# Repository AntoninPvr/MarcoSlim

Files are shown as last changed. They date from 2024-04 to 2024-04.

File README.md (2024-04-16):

<h1 align="center">
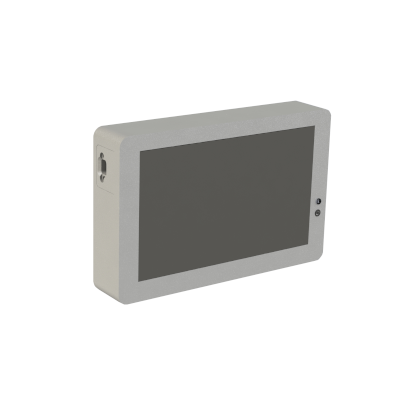
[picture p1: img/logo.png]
MarcoSlim Logo
    </a>
    <br>
    MarcoSlim
</h1>





    ⚠️ DISCONTINUED
    This project is discontinued and will not be updated anymore.
    Please refer to the new version of the Marco project

### New version MarcoX is available here : https://github.com/AntoninPvr/MarcoX

---

## Preface 
MarcoSlim is an upgrade of original Marco. Project had been launched during the 2023 BDE of Télécom Physique Strasbourg. Original Marco was based on Raspberry PI and old style resistive screen and 3 meters of cables and adapters hardly stuff in rectangular 3D printed case.

This new version is based on Orange PI zero 2W with a 7" capacitive touch screen. This modernized versiona aims to be more reliable and compact with a new RFID reader.

Software was also modernized and is available here : https://github.com/LOISGALLAUD/MARCONEO

Marco is a project that aims to create a payment terminal for a school BDE (French equivalent of Student Union). It is based on a RFID card system. The terminal is used by the students to pay for their meals or drinks. The terminal is connected to a self-hosted server that manages the accounts of the students. This terminal act as cash register.

This project is related to InsidePSBS app. Students can check their account and history on this mobile app available on IOS and Android. https://github.com/info-telecom-strasbourg/InsidePSBS (Reserved to TPS and ESBS students)

<p float="left">
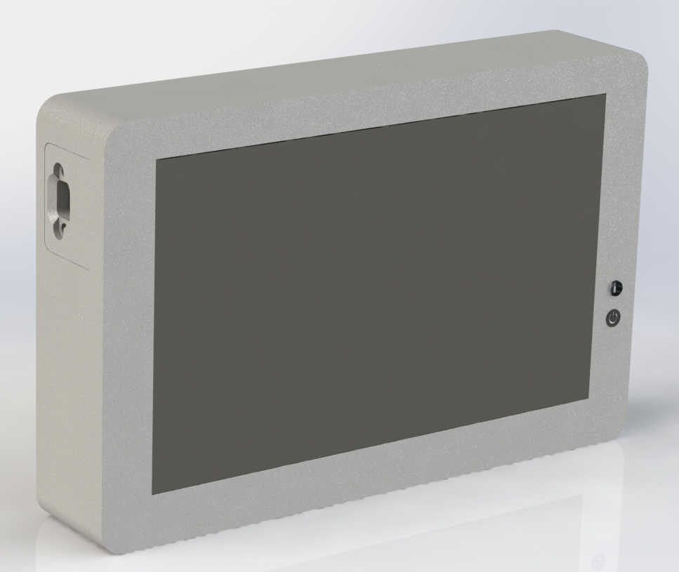
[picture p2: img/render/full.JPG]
  
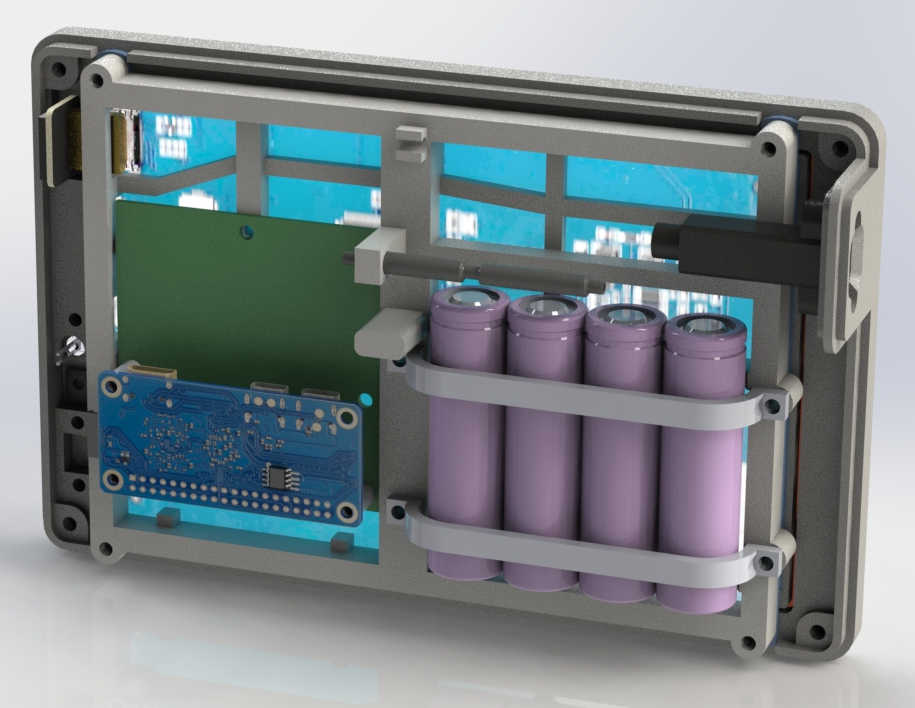
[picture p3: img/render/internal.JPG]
   
</p>

## Specifications

* **Screen**: 7" capacitive touch screen
* **RFID reader**: 125kHz compatible
* **Power supply**: USB-C 5V 3A
* **SBC**: Orange PI zero 2W
    * SoC: Allwinner H618 quad-core Cortex-A53 @ 1.5GHz
    * RAM: 1GB LPDDR4
    * Wi-Fi: 802.11 ac (Wi-Fi 5)
    * Bluetooth: 5.0
* **Battery**: 29.6Wh Li-ion (4x 3.7V 2000mAh)
* **Dimensions**:
    * Length: 200mm
    * Depth: 129mm
    * Height: 38mm

## Shopping list

### Electronic parts

* Orange PI zero 2W with 1GB RAM or more
* Micro SD card 16GB ore more, U3 speed class or more
* 7" Waveshare touch screen or compatible with HDMI input
* 125kHz RFID reader
* 4x 3.7V 2000mAh Li-ion battery
* USB-C power supply
* mini HDMI to HDMI 100mm cable: A2 to C1
* USB-C to micro usb 100mm cable: W3R to T1B
* USB-C pannel 17mm center distance mount connector 20mm

    ---

### Mechanical parts
* M4 screws 16mm x4
* M4 inserts x4
* M3 screws 10mm x15
* M3 inserts x15

    ---
### Parts details
| | |
|---|---|
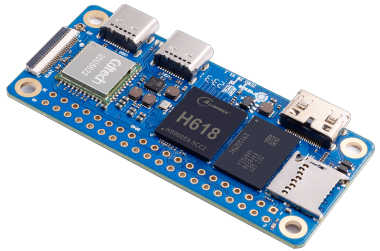
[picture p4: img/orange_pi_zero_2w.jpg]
Orange PI zero 2W
| Orange PI zero 2W |<p align="right"> 
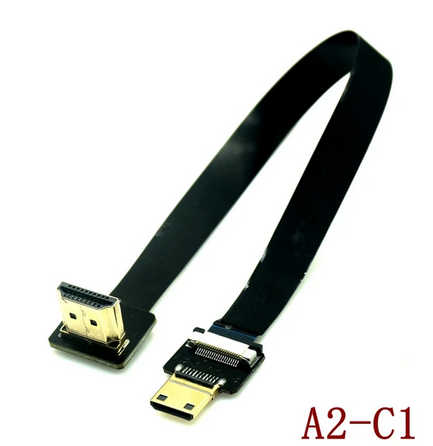
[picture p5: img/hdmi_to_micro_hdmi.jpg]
HDMI to Micro HDMI adapter
|Mini HDMI to HDMI 100mm cable: (A2 to C1). Large side of HDMI is on ribbon cable side. Mini HDMI large side is on ribbon connector side.  | |
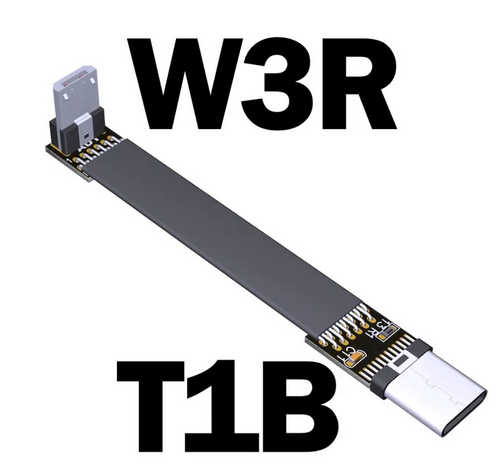
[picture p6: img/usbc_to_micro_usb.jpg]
HDMI to Micro HDMI adapter
|USB-C to micro usb 100mm cable: W3R to T1B||
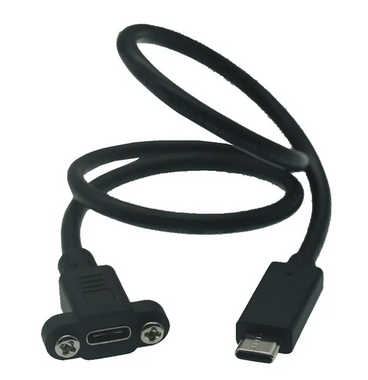
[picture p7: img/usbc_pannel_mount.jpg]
|USB-C pannel 17mm center distance mount connector 200mm||

### Screen

Screen is 7" Waveshare touch screen or compatible with HDMI input it can be a compatible one as long as it has the same connectors and the same size.

<p align="center">
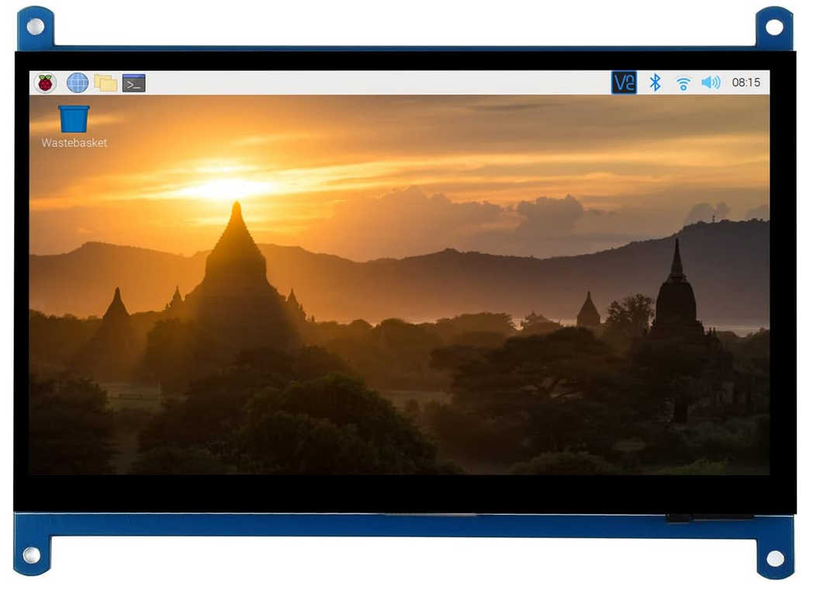
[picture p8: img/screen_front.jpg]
Front
    
&nbsp;
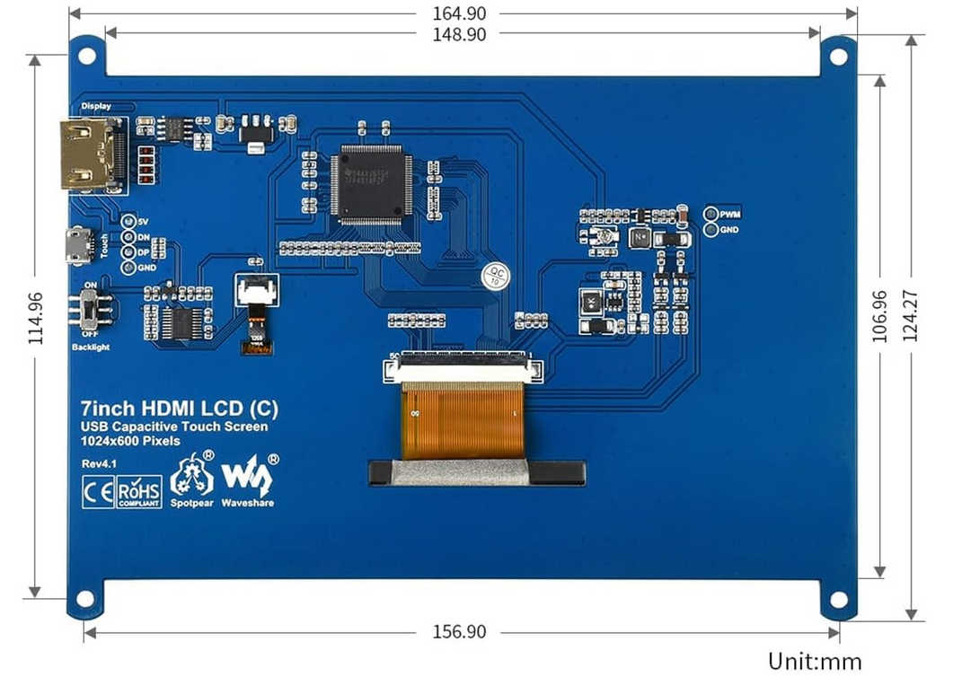
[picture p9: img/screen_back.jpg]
Screen BAck
    
</p>

## 3D printed parts

All parts are in `.stl` format. They are designed to be printed without support.

### Printer settings

Tested settings, but feel free to adapt them to your printer and material.:

* Layer height: 0.2mm
* Infill: 20%
* Nozzle diameter: 0.4mm
* Material: PLA or PETG

*Note: PTEG is recommended for better water and UV resistance.*

### All parts

<p align="center">
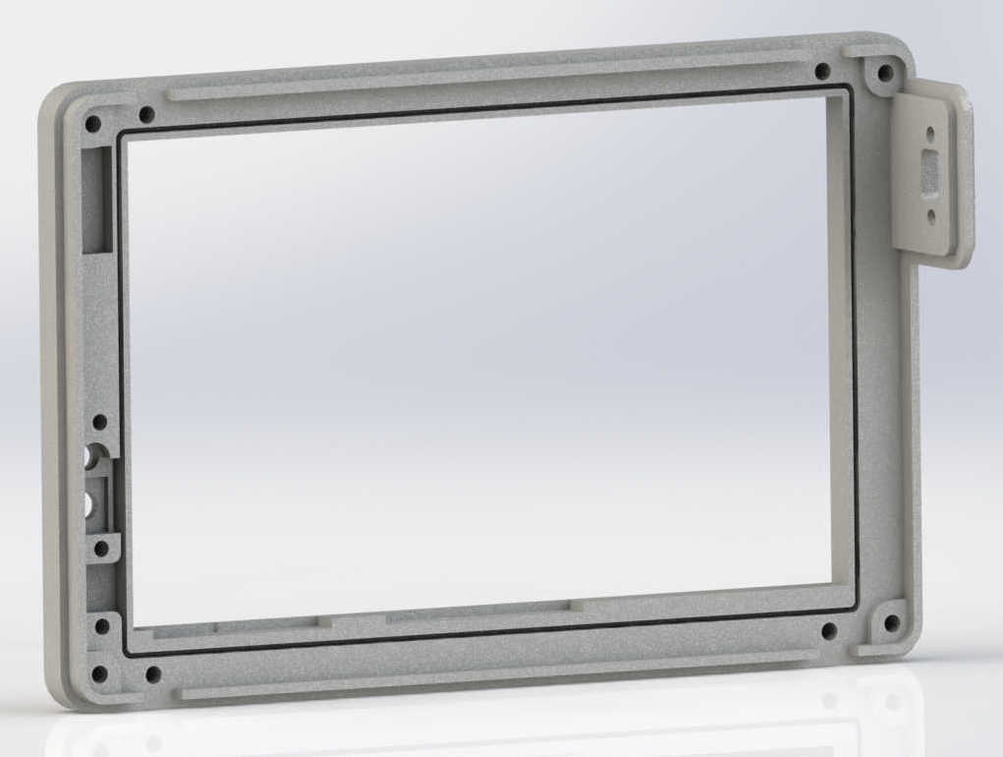
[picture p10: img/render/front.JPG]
Screen front
    
&nbsp;
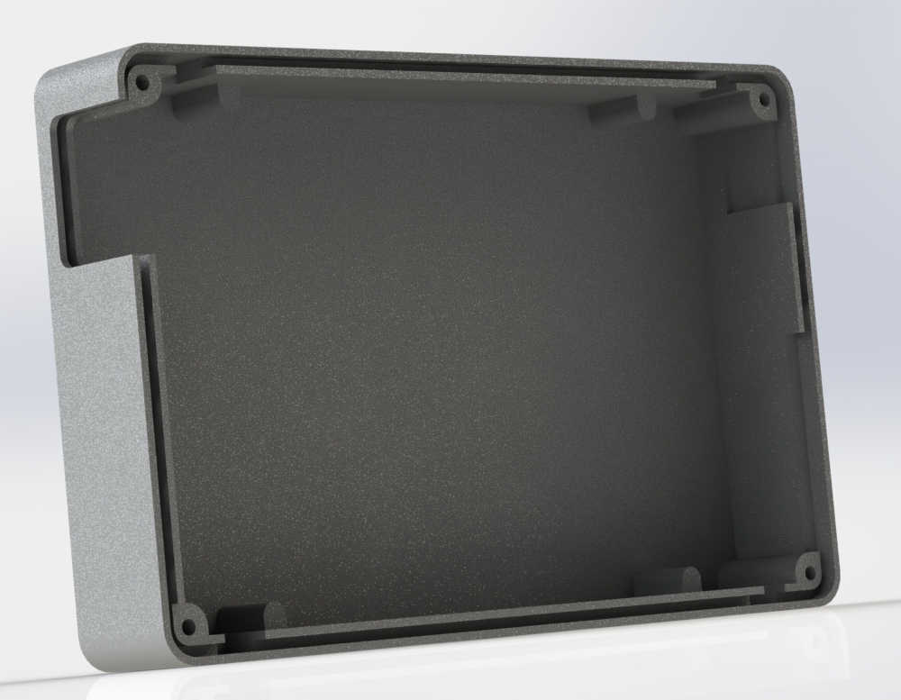
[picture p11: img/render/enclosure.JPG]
Cover
    
&nbsp;
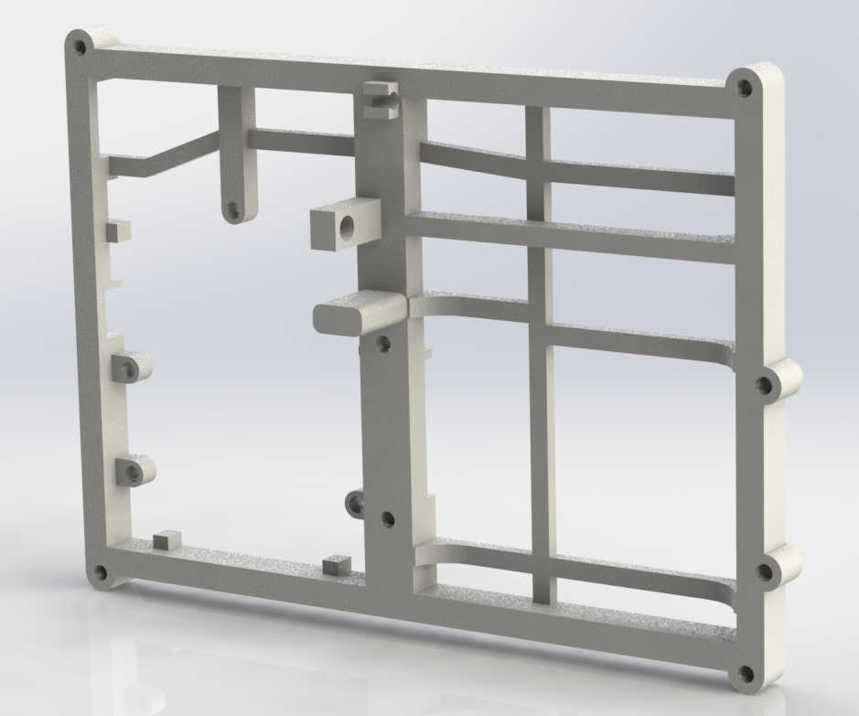
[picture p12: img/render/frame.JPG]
Frame
    
</p>

### Front

**File:** [front.STL](https://github.com/AntoninPvr/MarcoSlim/blob/main/front.STL)

The front cover hold the screen and allow it to be attached without overthickness. It also includes the RFID reader coil use for card detection, USB-C charging hole, power activity LED and Power button. This part is attached to the enclosure with 4 M4 screws, and provide a sort of seal to prevent dust and water to enter the enclosure.

*Note: clearance for sealing are very tight. This make 3D printing more difficult and printer dependent.*

### Internal frame

**File:** [internal_frame.STL](https://github.com/AntoninPvr/MarcoSlim/blob/main/internal_frame.STL)

This frame is attached to the screen and is used to mount Orange PI, Li-ion batteries, PCB and Wi-Fi antenna.

*Note: For this part adding support may improve print quality*

### Cover

**File:** [cover.STL](https://github.com/AntoninPvr/MarcoSlim/blob/main/cover.STL)

The back cover is used to close the enclosure. It is attached to the enclosure with 4 M4 screws.

*Note: clearance for sealing are very tight. This make 3D printing more difficult and printer dependent.*

### Orange PI Standoff

**File:** [orange_pi_standoff.STL](https://github.com/AntoninPvr/MarcoSlim/blob/main/orange_pi_standoff.STL)

Standoff are used to maintain Orange PI in place and add spacing for electronics components bellow. They are attached to the internal frame with 3 M3 screws.

### Battery holder 

**File:** [18650_4_holder.STL](https://github.com/AntoninPvr/MarcoSlim/blob/main/18650_4_holder.STL)

Battery holder is used to maintain 4 Li-ion batteries in place. It is attached to the internal frame with 4 M3 screws.

### Power button

**File:** [power_button.STL](https://github.com/AntoninPvr/MarcoSlim/blob/main/power_button.STL)

Power button.

## Electronics

### RFID reader

RFID reader is connected to Orange PI with either USB if the reader use is the classic USB reader that act as a keyboard or GPIO if the reader is custom made on PCB.

The RFID coil is placed in the front cover arround the screen. By this way the card can be detected by the reader when the card is hold in the user hand when he interact with the screen. This is a way to make the user experience more intuitive. Coil is connected to a tiny PCB with a connector that is attached to the front cover with 2 M3 screws. (see front cover bellow)

<p align="center">
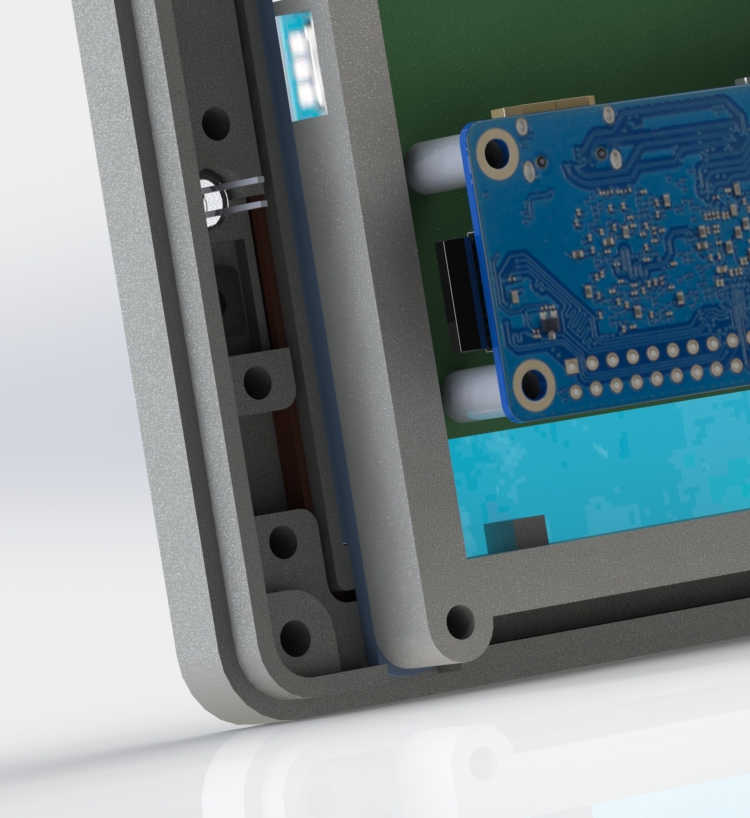
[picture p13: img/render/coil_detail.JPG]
Coil details
    
</p>

But the screen is made with a large metal plate that disturb the magnetic field of the coil. After multiple tests this idea was abandoned in favor of a more classic placement of the coil with the new MarcoX version.

### Power button and activity LED

Power button is connected to PCB with a 2 pin connector and trigger Orange PI zero 2W boot. It is placed in the front cover and is used to power on and off the terminal.

Activity LED is bicolor and connected to PCB with a 3 pin connector. It is placed in the front cover to indicate the charging status of the terminal.

<p align="center">
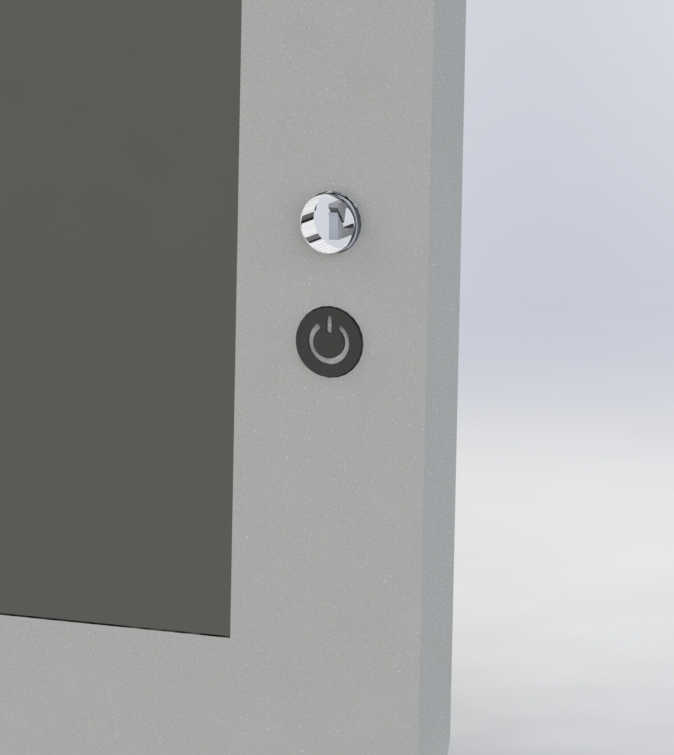
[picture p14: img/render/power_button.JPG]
    
</p>

## Related projects

* #### New version MarcoX is available here :
    > https://github.com/AntoninPvr/MarcoX

    <p align="left">
        
    &nbsp;
        
    &nbsp;
        
    </p>    
---

* #### Software associated with MarcoX is available here :
    > https://github.com/LOISGALLAUD/MARCONEO

    <p align="left">
        Screen front
    &nbsp;
        Screen BAck
    &nbsp;
        Screen BAck
    </p>
---

* #### Mobile App InsidePSBS source is available here :
    > https://github.com/info-telecom-strasbourg/InsidePSBS
    
<p align="right">
    <a href="https://app.its-tps.fr" target="_blank">
        
    </a>
 </p>

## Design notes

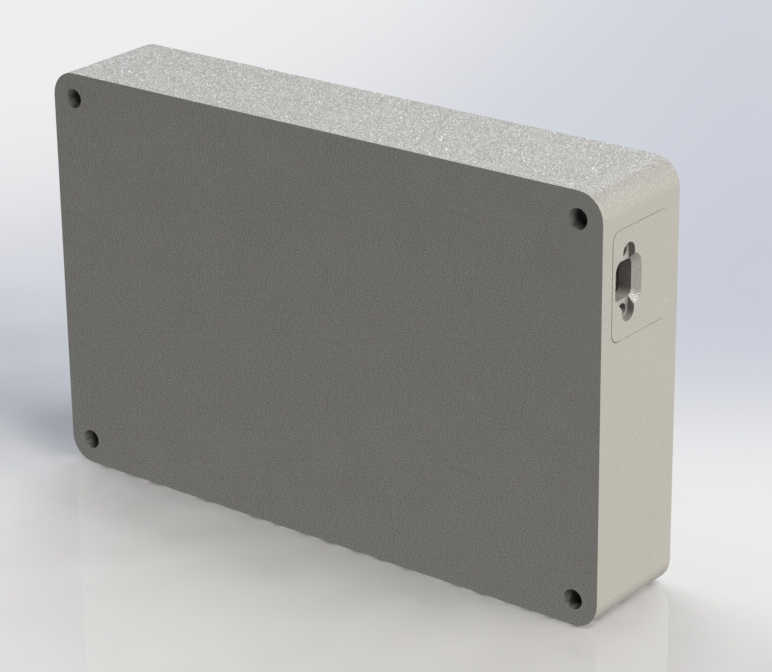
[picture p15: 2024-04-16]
img/render/back.JPG

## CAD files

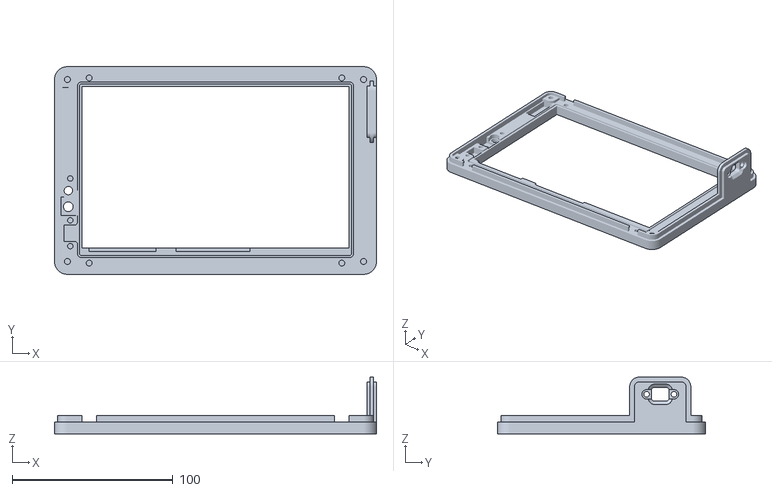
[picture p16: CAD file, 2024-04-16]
front.STL
200.0 x 129.0 x 35.3

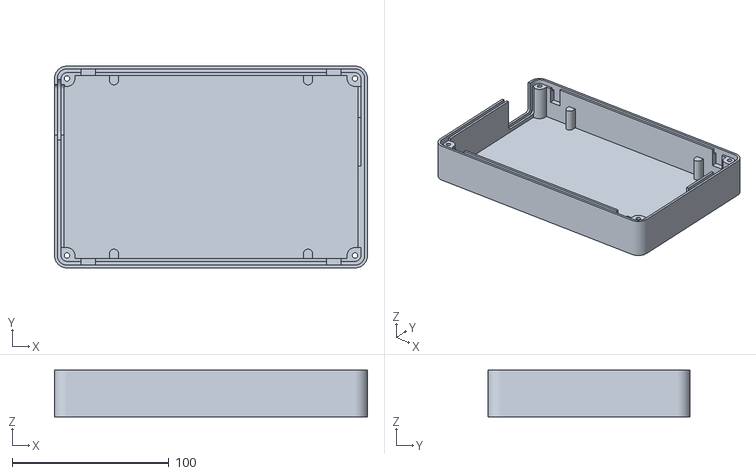
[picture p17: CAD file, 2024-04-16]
cover.STL
200.0 x 129.0 x 30.0

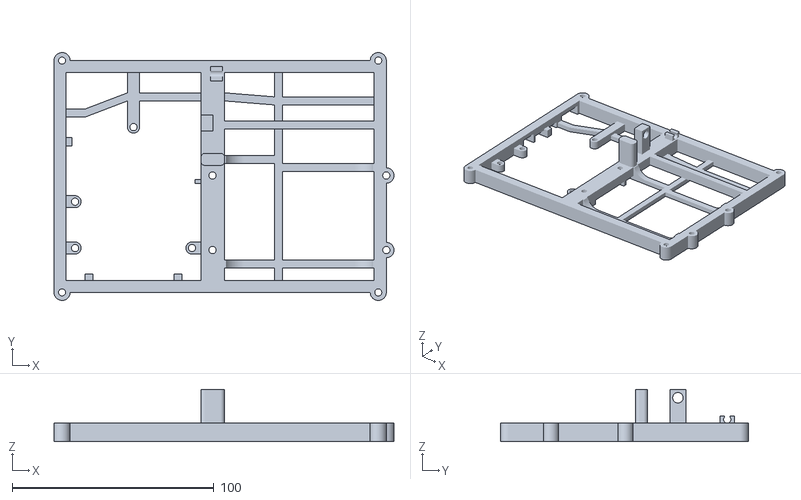
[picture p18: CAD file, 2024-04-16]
internal_frame.STL
168.7 x 123.0 x 26.0

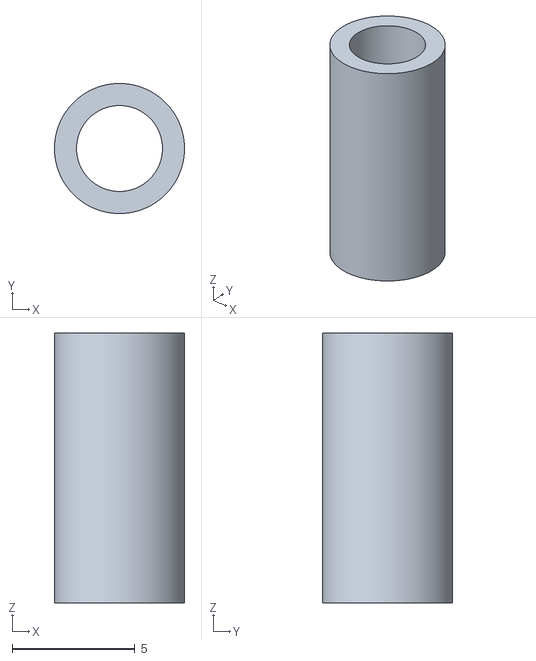
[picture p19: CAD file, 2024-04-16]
orange_pi_standoff.STL
5.30 x 5.30 x 11.0

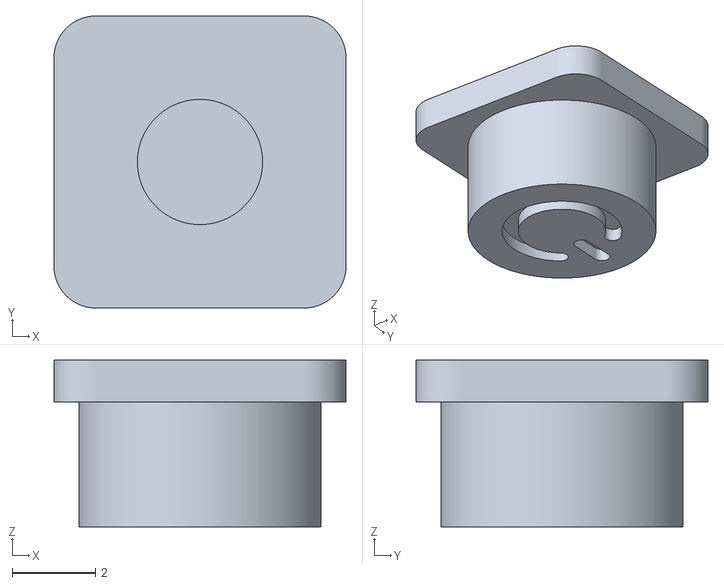
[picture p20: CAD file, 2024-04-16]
power_button.STL
7.00 x 7.00 x 4.00

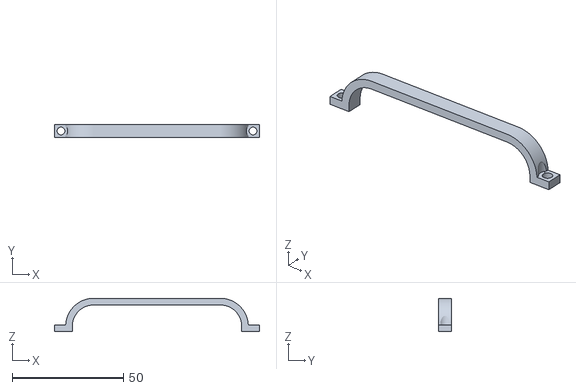
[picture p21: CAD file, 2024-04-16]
18650_4_holder.STL
92.0 x 6.00 x 15.0
